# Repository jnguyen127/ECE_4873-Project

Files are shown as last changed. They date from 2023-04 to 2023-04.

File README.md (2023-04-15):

# ECE4873 - Power Generation and Consumption Tracking
Repository revolved around using a clamp ammeter and microcontroller in order to monitor and track power consumption, and the data it recieves can be viewed on a web application. The folders included are as follow: "PowerTap" (Microcontroller program) and "Web_Application" (web application). The "MainPCB" (PCB cad) and "Lambda_Function" (automatically delete expired new accounts) are optional features of this device.

More information can be found on "Guide.html" by opening the file using any web browser.

* If you use this repo as a reference, make sure to give credit please.
* If there are any issues or concerns, please email John Nguyen: jhnguyen127@gmail.com!

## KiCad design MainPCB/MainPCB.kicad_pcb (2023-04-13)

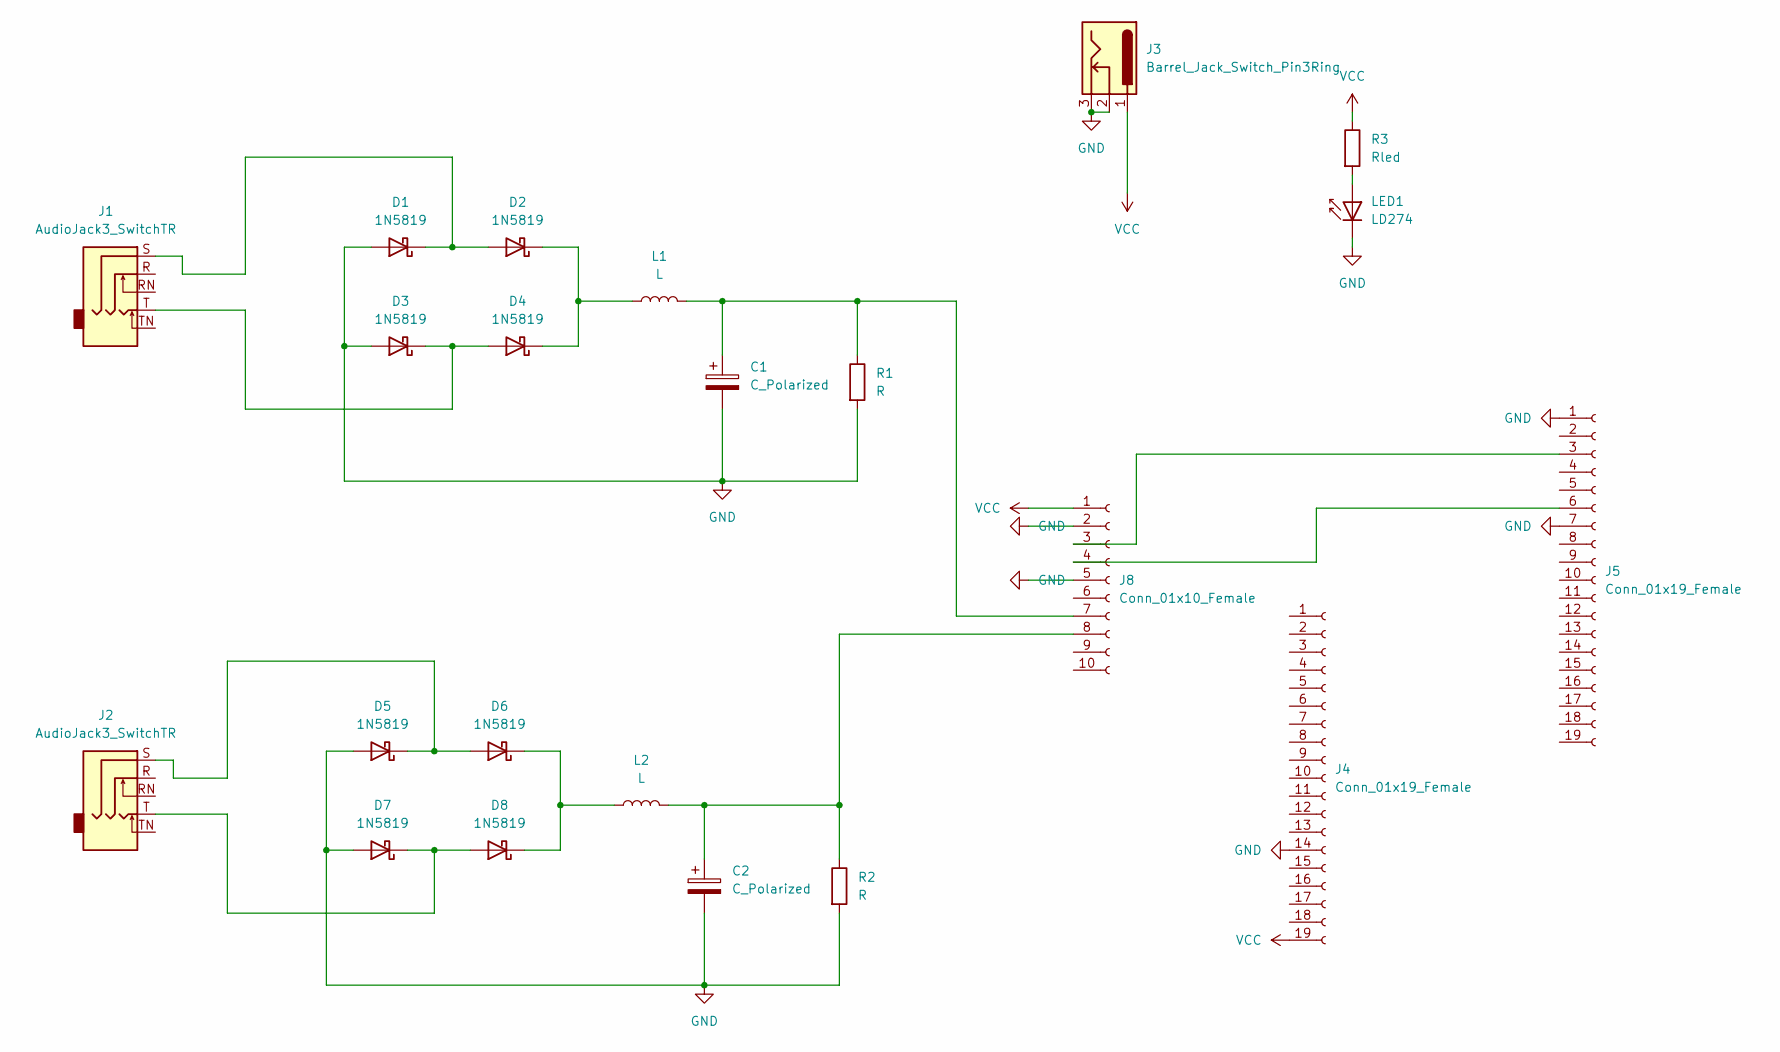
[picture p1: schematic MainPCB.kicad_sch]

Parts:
C1, C2: C_Polarized; C_Radial_D10.0mm_H20.0mm_P5.00mm
D1, D2, D3, D4, D5, D6, D7, D8: 1N5819; D_DO-41_SOD81_P10.16mm_Horizontal
J1, J2: AudioJack3_SwitchTR; Jack_3.5mm_Ledino_KB3SPRS_Horizontal
J3: Barrel_Jack_Switch_Pin3Ring; BarrelJack_Wuerth_6941xx301002
J4, J5: Conn_01x19_Female; PinHeader_1x19_P2.54mm_Vertical
J8: Conn_01x10_Female; PinHeader_1x10_P2.54mm_Vertical
L1, L2: L; L_Radial_D12.0mm_P5.00mm_Neosid_SD12k_style2
LED1: LD274; LED_D5.0mm_IRGrey
R1, R2: R; R_Axial_DIN0207_L6.3mm_D2.5mm_P10.16mm_Horizontal
R3: Rled; R_Axial_DIN0207_L6.3mm_D2.5mm_P10.16mm_Horizontal

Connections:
GND: C1.2, C2.2, D1.2 (A), D3.2 (A), D5.2 (A), D7.2 (A), J3.2, J3.3, J4.14, J5.1, J5.7, J8.2, J8.5, LED1.1 (K), R1.2, R2.2
unnamed: C1.1, J8.7, L1.2, R1.1
unnamed: C2.1, J8.8, L2.2, R2.1
unnamed: D1.1 (K), D2.2 (A), J1.S
unnamed: D2.1 (K), D4.1 (K), L1.1
unnamed: D3.1 (K), D4.2 (A), J1.T
unnamed: D5.1 (K), D6.2 (A), J2.S
unnamed: D6.1 (K), D8.1 (K), L2.1
unnamed: D7.1 (K), D8.2 (A), J2.T
unnamed: J5.3, J8.3
unnamed: J5.6, J8.4
unnamed: LED1.2 (A), R3.2
VCC: J3.1, J4.19, J8.1, R3.1

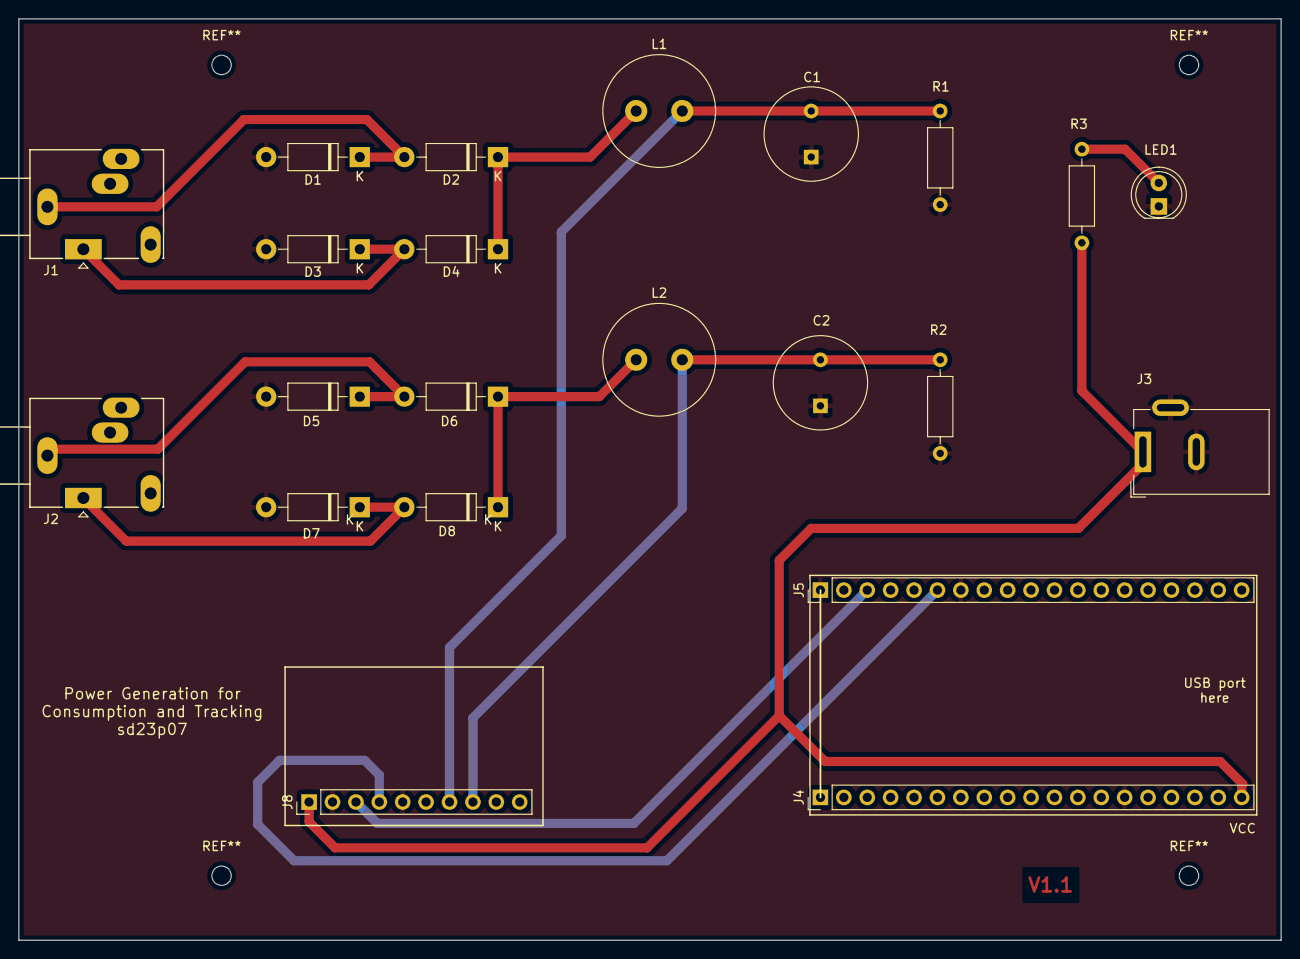
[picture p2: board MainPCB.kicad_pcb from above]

Board: 2 copper layers, 137.0 x 100.0 mm, 22 parts (0 on the bottom side), 13 nets.

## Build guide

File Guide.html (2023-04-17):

# Power Generation and Consumption Tracking

## Team Members

### Software Team

John Nguyen (https://www.linkedin.com/in/john-nguyen-ba8a951ab/)
Christopher Mack III

### Hardware Team

Joshua Synder
Michael Landon
Nickolas Lee
John Fontejon

# Table of Contents

Overview
(Optional) Lambda Function
1. AWS Account Setup
2. IAM Setup
3. EC2 Setup
4. SES Setup
5. DynamoDB Table Setup
6. IoT Core Setup
7. Microcontroller Setup
8. EC2 Connection Setup
9. Web Application
(Optional) Simulate Microcontroller
Parts
References

# Overview

The device's purpose is to determine how much power is being generated based from a clamp ammeter which reads and sends current readings to the microcontroller (ESP-32 WROOM-32D) which then sends those readings to a web application through Amazon Web Services (AWS), in graph or tabular form. This is a guide for replicating this.



Figure 1. Web application for this device



Figure 2. System-level diagram for this device



Figure 3. The device with hardware support for 2 clamp channels.

### Clamp System

The Clamp System is either a single clamp or group of clamps that is connected to the ADC (ADS1115), after it gets rectified, which sends its/their readings to the ADC. The ADC is able to handle up to 4 analog inputs at a single time which then outputs a 16-bit number that is associated with the analog input it received. Using I2C as a way to have communication between the ADC and the microcontroller.

The reason an external ADC is used instead of the internal ADC from the microcontroller is due to the precision. Testing without the external ADC showed that for small changes in voltages, the resolution was not good which we would lead to not as precise results. Having 4 extra bits greatly increased the resolution. However, there is also an advantage to using this external ADC since it uses I2C as a way to communicate with the microcontroller. Effectively, this means the number of clamps is much greater than 7. The ESP-32 WROOM-32D does have 15 ADC inputs however ADC2 cannot be used since WiFi is used.

Figure 2 shows that there is only one clamp attached. This is due to the limited time for this project, on the software side, and not because it is not possible. There is a second port for an additional clamp which serves as a proof of concept. Further modifications to the codes in the repo will be required in order to support more than one clamp.



Figure 4. Circuit block diagram for this device

### Microcontroller

The microcontroller runs a program that indefinitely sends its readings to a server, based on the Clamp System, until it is powered off. The server that will store data to be used for this application is AWS DynamoDB. The reason this was chosen is due to its simplicity as well as it is cost efficient. It scales automatically based on how much data the application requests/sends, and it can be cheap/free depending on how much load one uses. Additionally, AWS has an internet of thing service (AWS IoT Core) which enables a microcontroller to send data to its other services such as DynamoDB. In this application, MQTT requests are used to send data from the microcontroller's pins to AWS DynamoDB. In order to support more than one clamp, multithreading may be required since only one MQTT request can be sent at a time for the current code.

### Web Application

The web application is based on using Flask. This application has features such as a login system, a live graph of the data from the microcontroller, and more. This web application is hosted from an EC2 Instance through AWS. Any information, such as a user's login, will also be stored and sent to AWS DynamoDB. The web application can also be run through the user's personal system too, but this method allows user's not having to go through extra steps to install resources such as python and it won't hog system resources.

# (Optional) Lambda Function

This section is going to be dedicated for setting up "Lambda" which is a service provided by AWS that will be used to delete accounts that have not been verieid.

1. Using the search bar, search "Lambda" and click it.



2. Click "Create a function."



2. Copy the screenshot.



3. Paste the 2 files "lambda_function.py" and "env.py" from the "Lambda_Function" folder into the lambda. Then click "Deploy" to finish this step.



4. Then, if you want this to run automatically or on a schedule, you can use AWS's "CloudWatch" "Event Rule" to do this.

# 1. AWS Account Setup

This section is going to be dedicated for setting up a "free" AWS account.

1. Create an account by visiting here (https://aws.amazon.com/) and click "Get Started for Free."



2. Click "Create a Free Account".

NOTE: Please do read what this type of account does offer because it will charge you if you use more than what the free tier account offers.



3. Enter an email in "Root user email address" and an account name in "AWS account name" (i.e. Web_Application_Account). After that, click "Verify email address."



4. Check the email that was entered and enter the verification code from the email to verify that email's ownership. Click "Verify" after verification.



5. After verifying the email, create a password for the account and then click "Continue (step 1 of 5)."



6. Enter the information as asked by AWS and check the box off after reading the terms and services from AWS. Click "Continue (step 2 of 5)" to continue."



7. Enter billing information in the fields, and then click "Verify and Continue (step 3 of 5)" to continue."



8. Enter a phone number to verify the phone number, type the captcha text, and then click "Send SMS (step 4 of 5)."



9. Enter the code sent to the phone number and then click "Continue (step 4 of 5)."



10. Now select the "Basic support - Free" plan and then click "Complete Sign Up."



11. This should be the final screen after successfully creating an account. Click "Go to the AWS Management Console" (or sign in).



12. This is the home page for the AWS account. On the top right, click the drop down box that is to the left of the AWS account name, and select the region that is nearest to where the application will be running from. This is a crucial step for web application speed and consistency. In this example, the application is going to be near North Virginia so that is selected.

NOTE: Keep note of the region too as that will be needed later (i.e. us-east-1). Us-east-1 will be used for the reminder of this guide.



# 2. IAM Setup

## IAM User Creation

This next step is to give the web application, a user, access to DynamoDB which is where user data will be stored. Skipping this step would result in the web application not having access to data. Additionally, it will give access for the web application to send emails using AWS's Simple Email Service (SES) which will be explained later on how to set this service up.

1. Using the search bar, search "IAM" and click it.



2. At the IAM dashboard, click the number under "Users" in the "IAM resources" section.



3. Click "Add Users."



4. Add a user name for this user (i.e. Web_Application). Click "Next" after so.



5. Click "Attach policies directly" and add "AmazonDynamoDBFullAccess" by searching it under "Permissions policies" and check its checkbox. Do the same for "AmazonSESFullAccess." The number next to "Permissions policies" should have 2 in the numerator. These policies allow the web application to have full access of DynamoDB and SES. Click "Next."



6. Confirm that this is what the final page looks like and then click "Create user."



7. After creating the user, click the user's name.



8. Change the tab to "Security credentials" and then click "Create access key."



9. Select "Application running on an AWS compute service" and check the checkbox at the bottom. Click "Next."



10. Give a description for this access key like the following (optional). Click "Create access key."



11. Copy both the "Access key" and "Secret access key" since you will need them later. The keys are not recoverable if it is loss! These keys allow the Web Application to access the AWS resources directly. Click "Done" once the access keys have been copied.

NOTE: Do not share these access keys and do not store them in plaintext.



## IAM Role Creation

This next step is to give the microcontroller access to DynamoDB which is where user data will be stored. Skipping this step would result in the microcontroller not having access to send data.

1. Using the search bar, search "IAM" and click it.



2. At the IAM dashboard, click the number under "Roles" in the "IAM resources" section.



3. Click "Create role."



4. Select "AWS service." Search "IoT" under "Use cases for other AWS service:" and select the option as shown. Click "Next."



5. Click "Set permissions boundary - optional" and then click "Use a permissions obundary to control the maximum role permissions." Next, search up "AmazonDynamoDBFullAccess" and click the tick to add it as a permission. Click "Next."



6. Add a role name for this role (i.e. Microcontroller). Confirm that this is what the final page looks like and then click "Create role."





# 3. EC2 Setup

## EC2 Instance Security Group

This section is going to be dedicated for setting up a security group for the EC2 instance. This will allow any user to connect to the web application. Otherwise, they would not be able to.

1. Using the search bar, search "EC2" and click it.



2. Under the "Network & Security" section on the left column, click "Security Groups."



3. Click "Create security group."



4. Add a name and description for the security group (i.e. Web Application SG - Allows traffic) and then click "Add rule" under "Inbound rules."



5. Under "Type" change the dropdown to "All traffic." Under "Source" change the dropdown to "Anywhere-IPv4." Click "Create security group" to finish.



## EC2 Instance Creation

This section is going to be dedicated for setting up an EC2 instance which is "virtual machine" that will host the web application.

1. Using the search bar, search "EC2" and click it.



2. Under the "Instances" section on the left column, click "Instances."



3. Click "Launch instances."



4. Add a name for the instance (i.e. Web_Application). Then, under "Application and OS Images (Amazon Machine Image)" select Ubuntu as the OS. Next, under "Amazon Machine Image (AMI)" select "Ubuntu Server 22.04 LTS (HVM), SSD Volume Type."



5. Under "Instance type," ensure that "t2.micro" is selected. It should be selected by default.



6. Under "Key pair (login)," click "Create new key pair."



7. Add a name for the key pair (i.e. Web_Application_Key). Select "RSA" as the "Key pair type" and ".pem" as the "Private key file format." Click "Create key pair." It should have downloaded through the browser. Be sure this is kept somewhere for later steps. This key allows one to be able to SSH (connect) to the instance.

NOTE: Do not share this key.



8. Under "Network settings," click "Select existing security group" and select the security group that was created in the "EC2 Instance Security Group" section. The summary should closely resemble the one in the screenshot. Click "Launch instance" to finalize the setup.



9. The instance is created, and the instance can be seen running by looking at the "Instance state" tab.



# 4. SES Setup

This section is going to be dedicated for setting up the "Simple Email Service" which is a service provided by AWS that will be used to send emails to verify accounts and reset passwords.

1. Using the search bar, search "Amazon Simple Email Service" and click it.



2. Click "Verified identities" under "Configuration" and then click "Create identity".



3. Click "Email address" and then enter an email address that would need to receive emails using this service. Follow the instructions on the email to verify the email(s). Repeat steps 1 and 2 if needed.



4. The email address's status can be seen in the "Verified identities" tab under "Configuration." If it says "Verified," then the email can now receive emails using SES.



# 5. DynamoDB Table Setup

## DynamoDB Microcontroller Table Creation

This section is going to be dedicated for setting up the table that will store the microcontroller's data when it sends data.

1. Using the search bar, search "DynamoDB" and click it.



2. Click "Create table."



3. Add a name for the table, a partition key, and a sort key.

NOTE: Have "_TABLE" at the end of the table name since this is how the web application will look for this table.



4. Copy the screenshots below and then click "Create table."





## DynamoDB User Table Creation

This section is going to be dedicated for setting up the table that will store the user's data when it user's sign up for the web application.

1. Using the search bar, search "DynamoDB" and click it.



2. Click "Create table."



3. Add a name for the table, and a partition key.



4. Copy the screenshots below and then click "Create table."





# 6. IoT Core Setup

## IoT Add Thing

This section is going to be dedicated for setting up the microcontroller using "IoT Core" from AWS. This is going to register the device to AWS.

1. Using the search bar, search "IoT Core" and click it.



2. In the "Manage" section, click "All devices" to open a drop down menu and then click "Things."



3. Click "Create things."



4. Select "Create single thing" and then click "Next."



5. Add a name for the "thing" (i.e. Microcontroller), but make sure to make this the same name as the table in the previous section DynamoDB Microcontroller Table Creation, step 3 (i.e. MICROCONTROLLER_TABLE), without the "_TABLE" portion. Then, select "No shadow" in the "Device Shadow" section. Click "Next" after doing so.

NOTE: This name should be "registered" in the "Account Info" page on the web application (without the table portion). The web application will use this IoT name to "automatically" reference the table that was created for it.



6. Select "Auto-generate a new certificate (recommend)" and then click "Next."



7. Click "Create policy."



8. Add a name for the policy (i.e. Microcontroller) and then click "JSON" underneath the "Policy statements" tab.



9. In the "Policy document" text window, paste the following text into it. The purpose of these policy statements is to define what "topics" the microcontroller would be using to communicate with AWS using MQTT.

{ "Version": "2012-10-17", "Statement": [ { "Effect": "Allow", "Action": "iot:Connect", "Resource": "arn:aws:iot:<REGION>:<ACCOUNT_ID>:client/<THING_NAME>" }, { "Effect": "Allow", "Action": "iot:Subscribe", "Resource": "arn:aws:iot:<REGION>:<ACCOUNT_ID>:topicfilter/<THING_NAME>/sub" }, { "Effect": "Allow", "Action": "iot:Receive", "Resource": "arn:aws:iot:<REGION>:<ACCOUNT_ID>:topic/<THING_NAME>/sub" }, { "Effect": "Allow", "Action": "iot:Publish", "Resource": "arn:aws:iot:<REGION>:<ACCOUNT_ID>:topic/<THING_NAME>/pub" } ] }

NOTE: Replace <REGION> with the account's region (i.e. us-east-1) which can be found next to the AWS account name. Replace <ACCOUNT_ID> with the AWS "Account ID" which can be found in the AWS account name's drop down menu, without the dashes. Also, replace <THING_NAME> with the IoT name (i.e. Microcontroller).



10. Below is an example of what the policy may look like when based on the "us-east-1" region which is in "North Virginia." After finishing, click "Create."



11. After creating the policy, go back to the original tab before clicking "Create policy" and then check off the policy that was just created. Click "Create thing."



12. This is the final and crucial step. Download "Device certificate," "Public key file," "Private key file," and "RSA 2048 bit key: Amazon Root CA 1." This will need to be provided to the IoT in a separate step so save this.



## IoT Add Rule

This section is going to be dedicated for setting up the microcontroller's behavior by defining a rule when it publishes a MQTT message.

1. Using the search bar, search "IoT Core" and click it.



2. In the "Manage" section, click "Message routing" to open a drop down menu and then click "Rules."



3. Add a name for the rule (i.e. Microcontroller_Publish) and a description (if desired). Click "Next" afterwards.



4. In "SQL version," select "2016-03-23" as the version, and then copy and paste the following text into "SQL statement". Click "Next" after finishing this step.

SELECT * FROM '<THING_NAME>/pub'

NOTE: The text after "FROM" in the SQL statement, should be exactly the same as one of the policy statements from the previous section, step 9.



5. Under "Rule actions" click the drop down box and select "DynamoDBv2."





6. Select "Table name," and select the table that was created to store the microcontroller's data. Also, select "IAM role" and select the role that was created in the previous "IAM Role Creation" (i.e. Microcontroller) section. Click "Next" after those previous steps.







7. Double check that the IoT rule is correct and then click "Create."



# 7. Microcontroller Setup

## Arduino Setup

This section is going to be dedicated for setting up the environment to program the microcontroller using Arduino IDE and Windows 10 64-bit as the OS.

1. Go to Arduino (https://www.arduino.cc/en/software) to download the IDE.



2. After installing Arduino IDE, open it and go to the "Library Manager" (the books icon) and install the following libraries.



3. Then, go to "File," "Preferences," and then "Additional Board Manager URLs" and paste these URLs. Click "Ok" to finalize this step.

• https://raw.githubusercontent.com/espressif/arduino-esp32/gh-pages/package_esp32_index.json
• http://arduino.esp8266.com/stable/package_esp8266com_index.json





4. Now, go to the "Board Manager" (the second icon) and install the following board.



5. Finally, go to Silabs (https://www.silabs.com/developers/usb-to-uart-bridge-vcp-drivers?tab=downloads) to download the USB to UART to be able to program the microcontroller. Extract the zip file and then run and install "CP210xVCPInstaller_x64.exe"



# Configure the Program

1. Before programming the microcontroller, the program needs to be configured to be able to connect to AWS IoT Core. In the "PowerTap" folder, open "config.h" using any text editor. Then, fill out all of the empty variables. The "THINGNAME" was done in step 5 of the section IoT Core Setup. (i.e. Microcontroller). "AWS_IOT_PUBLISH_TOPIC" and "AWS_IOT"SUBSCRIBE_TOPIC" is also in step 10 of of the section IoT Core Setup. (i.e. "Microcontroller/pub" and "Microcontroller/sub," respectively). "WIFI_SSID" and "WIFI_PASSWORD" is just the WiFi. it would connect to in order to have access to AWS. "AWS_IOT_ENDPOINT" can be found in the screenshot. The rest of the variables are the IoT's certificates and key which was in step 12 of the section IoT Core Setup. Just match the file extension the comment of the config file indicates (the "...-public.pem.key" will not be used).



## Programming the Microcontroller

This section is going to be dedicated for programming the microcontroller.

1. Go to "File" and then "Open" and open the sketch provided by the repo called "PowerTap.ino."



2. Click the drop down and click "Select other board and port."

NOTE: Make sure the board is plugged in for this step.



3. Select the port and select "ESP32 Dev Module." Click "Ok" to close the window.



4. Now, to program board, click the "Upload" button. Hold down the "BOOT" button on the ESP32 until it goes past "Connecting..." It should start writing, and then it will say "Leaving... Hard resetting via RTS pin..." This means it has successfully been programmed!





# 8. EC2 Connection Setup

## EC2 SSH Setup

This section is going to be dedicated for setting up the environment to SSH into the EC2 instance using MobaXTerm and Windows 10 64-bit as the OS.

1. Go to MobaXterm (https://mobaxterm.mobatek.net/download.html) to download the IDE.



3. Go to the directory that has the "Web_Application_Key.pem" that was downloaded from the EC2 Instance Creation section step 7. Hold shift and right click the file, and click "Copy as path."



2. Open MobaXterm and click "Start local terminal."



4. Type "cd" and then paste (right click) the path with a space between cd and the path. Also, remove the actual file from the path. The final line should look like this.



5. Go to AWS and using the search bar, search "EC2" and click it.



6. Under the "Instances" section on the left column, click "Instances."



7. Now, check off the instance that was created and then click "Connect"



8. Go to the "SSH client" tab and copy the "ssh -i "Web_Application_Key.pem ..." line and paste it (right click) into MobaXterm. The second screenshot is what should show up once you have successfully connected to the instance.





# EC2 Transfer Web Application

This will quickly go over how to add files to the instance using MobaXterm.

1. After connecting to the instance, drag over the folder "Web_Application" in the repo into the left column of MobaXterm. The folder should show up on the left hand side.





## EC2 Python Packages Setup

In order to run the web application using the instance, it needs some python packages. This will go over how to install those packages.

1. In sequential order, type these into the terminal and execute it. If it prompts, press "Enter."

• sudo apt update
• sudo apt install software-properties-common
• sudo apt update
• sudo add-apt-repository ppa:deadsnakes/ppa
• sudo apt-get update
• sudo apt install python3.8
• sudo apt install virtualenv
• virtualenv -p /usr/bin/python3.8 ./venv
• source venv/bin/activate
• sudo apt-get install python3.8-distutils
• cd "Web_Application"
• pip install -r requirements.txt

# 9. Web Application

## Configure Web Application

1. In order to run the web application, the configuration of one of the files needs to be filled out. In the "Web_Application" folder open "env.py," using any text editor, and fill out all of the variables. The "AWS_ACCESS_KEY" and "AWS_SECRET_ACCESS_KEY" was downloaded at step 7 of the EC2 Instance Creation section." "AWS_REGION" can be found at the top right of the AWS home page next to the account name. "SES_SOURCE" is the email that would be sending emails to other users using SES. This email needs to be verified through SES too. "SECRET_SALT" and "FLASK_SECRET_KEY" should be complex and different. These are "seeds" that determine how the web application will encrypt and decrypt certain components (i.e. a user password).

NOTE: There is a global variable called "offset" that needs to be configured when running the web application. It should print the current time + some delay (to allow the microcontroller to post the data first) into the terminal of MobaXTerm. If that time does not match the time zone of the microcontroller, the web application will not be able to retrieve the data from the table until hours later.

## Running Web Application

1. To run the web application, just follow this one step. Note that this will have to be done, sequentially, everytime MobaXterm refreshes/closes. The screenshot below shows what it should look like when the web application is running.

• Open MobaXterm and click "Start local terminal"
• SSH into the EC2 Instance
• source venv/bin/activate
• cd "Web_Application"
• python3.8 app.py runserver 0.0.0.0:5000



# Access Web Application

1. To access the web application, just paste the same "ec2-X-XX-XXX-XXX.compute-1.amazonaws.com" but with ":5000" at the end of it into a web browser (i.e. ec2-X-XX-XXX-XXX.compute-1.amazonaws.com:5000). If this is what shows up at the URL, congratulations, access to the web application has been successful.



# (Optional) Simulate Microcontroller

Ideally an actual microcontroller should be sending data, the optional "Simulate_Microcontroller.py" code in the "Web_Application" folder is used to "simulate" the microcontroller by sending data to the DynamoDB table. You can run this python code for testing purposes. Just fill in the user's email that you intend on testing on under the "email" variable.

# Parts

• 1 SCT013 (100A:50mA) Clamp Current Transformer
• 1 ESP32-WROOM-32D
• 8 Schottky diodes
• 2 332 inductors
• 2 1000uF, 25V capacitors
• 2 100ohm resistors
• 1 1kohm resistor
• 1 LED
• 1 16-bit I2C ADC+PGA ADS1115 by Adafruit
• 1 2.1mm Barrel Jack Socket with Integrated Rocker Switch
• 2 3.5mm Headphone Jack Socket 5Pin

# References

Flask Web Application (https://gtvault.sharepoint.com/:b:/s/ECE4873-PowerPeople/EV_7p87y0hVCrJAZ1RK-Tt0B3xnY0vjJ4eOIBT4Lj31fVg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)
Responsive Navigation Bar (https://youtu.be/oLgtucwjVII)
Responsive Login Form using HTML and CSS (https://www.youtube.com/watch?v=9XKRNfPrNpM)
AWS DynamoDB Pricing (https://dashbird.io/knowledge-base/dynamodb/dynamodb-pricing/)
Real Time Chart Example with Flask (https://ron.sh/creating-real-time-charts-with-flask/)
How to Display Clicked Data Points in the Table in Chart JS (https://www.youtube.com/watch?v=Cf5Vyt8nSDo)
How to Create a Table from Datasets in Chart JS (https://www.youtube.com/watch?v=O55kz7Yriog)
ESP-32 Current Time (https://lastminuteengineers.com/esp32-ntp-server-date-time-tutorial/)
AWS IoT: Storing IoT data into DynamoDB Database (https://youtu.be/ktQoA4LV__w)
JSON with Decimal (https://stackoverflow.com/questions/31202956/json-typeerror-decimal34-3-is-not-json-serializable)
Password Hashing with Flask (https://pythonprogramming.net/password-hashing-flask-tutorial/)
Filtering Data on Chart JS (https://www.youtube.com/watch?v=cz2rG-OVXXU)
Send data from ESP-32 to DynamoDB Setup AWS Example (https://github.com/nithin-k-shine/Sending-sensor-data-from-ESP32-to-AWS-DynamoDB-cloud-storage)
Send data from ESP-32 to DynamoDB Code Example (https://how2electronics.com/connecting-esp32-to-amazon-aws-iot-core-using-mqtt/)
Time API (https://cplusplus.com/reference/ctime/tm/)
Using Chart JS with Flask (https://www.youtube.com/watch?v=geKvJbQsOmM)
Analog Read with ESP-32 (https://randomnerdtutorials.com/esp32-adc-analog-read-arduino-ide/)
ESP-32 Specifications (https://docs.espressif.com/projects/esp-idf/en/latest/esp32/hw-reference/esp32/get-started-devkitc.html)
AC Rectifier Concept (https://www.youtube.com/watch?v=5cbQNfO0Mwg)
ADS1115 - ADC with I2C Serial Communication (https://www.adafruit.com/product/1085)

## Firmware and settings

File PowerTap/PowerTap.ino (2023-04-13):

#include "config.h"

#include <WiFiClientSecure.h>
#include <MQTTClient.h>  //MQTT Library Source: https://github.com/256dpi/arduino-mqtt

#include <ArduinoJson.h>  //ArduinoJson Library Source: https://github.com/bblanchon/ArduinoJson
#include "WiFi.h"

#include "time.h"
#include "sntp.h"

#include <Wire.h>
#include <Adafruit_ADS1X15.h>

Adafruit_ADS1115 ads;
WiFiClientSecure wifi_client = WiFiClientSecure();
MQTTClient mqtt_client = MQTTClient(256);  //256 indicates the maximum size for packets being published and received.
void connectAWS() {
  //Begin WiFi in station mode
  WiFi.mode(WIFI_STA);
  WiFi.begin(WIFI_SSID, WIFI_PASSWORD);

  Serial.println("Connecting to Wi-Fi");

  //Wait for WiFi connection
  while (WiFi.status() != WL_CONNECTED) {
    delay(500);
    Serial.print(".");
  }
  Serial.println();

  // Configure wifi_client with the correct certificates and keys
  wifi_client.setCACert(AWS_CERT_CA);
  wifi_client.setCertificate(AWS_CERT_CRT);
  wifi_client.setPrivateKey(AWS_CERT_PRIVATE);

  //Connect to AWS IOT Broker. 8883 is the port used for MQTT
  mqtt_client.begin(AWS_IOT_ENDPOINT, 8883, wifi_client);

  //Set action to be taken on incoming messages
  mqtt_client.onMessage(incomingMessageHandler);

  Serial.print("Connecting to AWS IOT");

  //Wait for connection to AWS IoT
  while (!mqtt_client.connect(THINGNAME)) {
    Serial.print(".");
    delay(100);
  }
  Serial.println();

  if (!mqtt_client.connected()) {
    Serial.println("AWS IoT Timeout!");
    return;
  }

  //Subscribe to a topic
  mqtt_client.subscribe(AWS_IOT_SUBSCRIBE_TOPIC);

  Serial.println("AWS IoT Connected!");
}

void publishMessage() {
  //Create a JSON document of size 200 bytes, and populate it
  //See https://arduinojson.org/
  StaticJsonDocument<200> doc;
  struct tm timeinfo;
  if (!getLocalTime(&timeinfo)) {
    Serial.println("No time available (yet)");
    return;
  }
  // Converting time to a desired time format
  String month = String(timeinfo.tm_mon + 1);
  if (month.length() == 1) {
    month = "0" + month;
  }
  String day = String(timeinfo.tm_mday);
  if (day.length() == 1) {
    day = "0" + day;
  }
  String year = String((timeinfo.tm_year + 1900) % 100);
  String hour = String(timeinfo.tm_hour);
  if (hour.length() == 1) {
    hour = "0" + hour;
  }
  String minute = String(timeinfo.tm_min);
  if (minute.length() == 1) {
    minute = "0" + minute;
  }
  String second = String(timeinfo.tm_sec);
  if (second.length() == 1) {
    second = "0" + second;
  }
  doc["Timestamp"] = month + "-" + day + "-" + year + " " + hour + ":" + minute + ":" + second;
  doc["Location"] = "Room 1";
  ADC = ads.readADC_SingleEnded(0); // Read the ADC Value
  if (ADC < 0) voltage = 0.0;
  else voltage = (ADC * 0.1875)/1000; // Convert ADC to voltage
  float conversion_factor = 20 * 120;
  float power = voltage * conversion_factor;
  doc["Power"] = power;
  char jsonBuffer[512];
  serializeJson(doc, jsonBuffer);  // print to mqtt_client
  //Publish to the topic + Sends jsonBuffer to dynamoDB based on Rule
  mqtt_client.publish(AWS_IOT_PUBLISH_TOPIC, jsonBuffer);
  Serial.println("Sent JSON: " + String(jsonBuffer));
}

// Can send messages from AWS to the IoT
void incomingMessageHandler(String &topic, String &payload) {
  Serial.println("Message received!");
  Serial.println("Topic: " + topic);
  Serial.println("Payload: " + payload);
}

// Callback function (get's called when time adjusts via NTP)
void timeavailable(struct timeval *t) {
  Serial.println("Got time adjustment from NTP!");
}

void setup() {
  ads.begin(); // Start the ADC
  Serial.begin(115200);
  // set notification call-back function
  sntp_set_time_sync_notification_cb(timeavailable); /**
   * NTP server address could be aquired via DHCP,
   *
   * NOTE: This call should be made BEFORE esp32 aquires IP address via DHCP,
   * otherwise SNTP option 42 would be rejected by default.
   * NOTE: configTime() function call if made AFTER DHCP-client run
   * will OVERRIDE aquired NTP server address
   */
  sntp_servermode_dhcp(1);                           // (optional)
  /**
   * This will set configured ntp servers and constant TimeZone/daylightOffset
   * should be OK if your time zone does not need to adjust daylightOffset twice a year,
   * in such a case time adjustment won't be handled automagicaly.
   */
  configTime(gmtOffset_sec, daylightOffset_sec, ntpServer1, ntpServer2);

  connectAWS();
}

void loop() {
  publishMessage();
  mqtt_client.loop();
  delay(1000);
}
